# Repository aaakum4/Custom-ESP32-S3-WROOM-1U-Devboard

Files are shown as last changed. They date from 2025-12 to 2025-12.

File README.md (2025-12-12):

# ESP32-S3 Devboard Project
This is my custom ESP32-S3-WROOM-1U devboard project. I loosely followed Kai’s guide, but made a bunch of changes along the way to fit the ESP32-S3 and to learn more about PCB design. The board includes USB-C power, a MicroSD slot, UART, JTAG, reset/boot buttons, and an I²C connector — plus some custom Gojo artwork because why not.

## BOM (Initial Planning)
- 2.4GHz antenna (https://www.ebay.com.au/itm/227057783591?itemid=526207835011_227057783591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)

- Touch Screen (https://core-electronics.com.au/2-8-tft-display-240x320-with-capacitive-touchscreen.html)
A possible later addition

- USB-C Power (https://jlcpcb.com/partdetail/Korean_HropartsElec-TYPE_C_31_M12/C165948)

- Switch (https://jlcpcb.com/partdetail/XUNPU-TS_1088AR02016/C720477)

- https://www.arrow.com/en/products/1040310811/molex?utm_source=chatgpt.com

- https://core-electronics.com.au/male-pin-header-2-54mm-1x40.html

** Note much of these aren't used, but I thought I'd leave them here in-case anybody wants to do a similar project, here are some ideas.

## Bill of Materials (BOM)

BOM
** This list is by no means perfect.

## Development Journal
Here’s the whole journey from start to finish.

## Researching Devboards
Before I even started, I had to figure out what a devboard actually is and what they’re used for. I knew I wanted to make my own, but I didn’t know much beyond that.
I spent a while reading, asking ChatGPT questions, and checking out examples online. I also made a plan for how my board would differ from the guide.



## Power System & USB-C
I started wiring up the power section first. At one point I went down the rabbit hole of trying to use a buck switching regulator, but eventually realised I was overcomplicating things.
So I scrapped that and switched to the MCP1700 LDO instead — way simpler and fits the project better.





## First Schematic Pass
Once I switched to the ESP32-S3 (instead of the RP2040 used in the guide), things got a lot more complicated. The datasheet helped, but there were still a ton of questions.
With help from Slack and ChatGPT, I put together the first full version of the schematic. Definitely not perfect, but it was a solid starting point.



## Finalising the Schematic
After some feedback from Reddit, I made a bunch of improvements and finally wrapped the schematic up.
At this point the board had everything I wanted: USB-C, MicroSD, UART, JTAG, reset/boot buttons, and I²C.
The hardest part was honestly just knowing whether what I did was correct, but the community feedback helped a ton.



## Footprint Assignment
Assigning footprints was next. Most were easy thanks to the guide, but a couple (like the MicroSD slot and ferrite bead) weren’t.
After some datasheet hunting, I got them sorted out without too much trouble.



## Organising Components
This part was surprisingly fun. At first I felt overwhelmed by the wall of random capacitors and resistors, but after spending a bit of time on it everything started to make sense.



## Routing + Adding Artwork
Routing took forever — easily the longest part. This is only the second PCB I’ve ever routed, so I spent a lot of time learning and undoing mistakes.
Two big things I learned:
- USB D+ and D− need to be the same length
- MicroSD lines should avoid vias if possible
After a bunch of restarts and hours of routing, I finally got it into a place I’m happy with.
** Note: A good peice of advice I got from Kai's guide was to not route ground and instead do a ground fill, this saved alot of time and actally looks really nice.
I also added Gojo artwork on the front and back because the board needed some personality.
Another important part was removing alot of the labeling like 'C6' for capacitor 6, it makes the board look alot cleaner.







## Creating the Production ZIP
Before exporting anything, I did a full DRC check and gave the whole PCB a final look over.
The Gerbers and drill files exported fine, but the BOM and footprint position files needed their headers renamed so the manufacturer will accept them:
Footprint Position Fixes
- Ref → Designator
- PosX → Mid X
- PosY → Mid Y
- Rot → Rotation
- Side → Layer

BOM Fix
- Designation → Comment

After fixing those, I zipped everything up into a production-ready file.



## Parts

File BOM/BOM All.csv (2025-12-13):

BOM Table
JLCPCB BOM Tool - BOM Matching
BOM name_Devboard Routed Backup-JLCPCB Assembly Order.xlsx |  |  | Download Time_2025-12-13 15:56:26 |  |  |  | * Our matching results are updated in real-time, but stock and prices may change. If it's been over 24 hours, please re-match before placing your order.
PCB Assembled Qty_5 |  |  | Est. Total Price_3.9206
Your BOM |  |  |  |  | Matched Parts |  |  |  |  |  |  | Order Information
Top Designator | Bottom Designator | Comment | Footprint | JLCPCB Part # | Matches | Part # | Manufacturer | Footprint | Description | Category | Warning | JLCPCB Part # | Product link | Lib Type | Qty | Source | Total Price ($)
C3,C5,C7,C6 |  | 0.1uF | C_0402_1005Metric |  | Select by Customer | CL05B104KO5NNNC | Samsung Electro-Mechanics | 402 | 100nF 16V X7R ±10% 0402 Multilayer Ceramic Capacitors MLCC - SMD/SMT ROHS | Multilayer Ceramic Capacitors MLCC - SMD/SMT | 1.The comment (CL05B104KO5NNNC) of this part does not match the one (0.1uF) provided in your BOM. Please confirm; | C1525 | https://jlcpcb.com/partdetail/1877-CL05B104KO5NNNC/C1525 | Basic | 8 | 8 JLCPCB | 0.0096
C4 |  | 22uF | C_0603_1608Metric |  | Select by Customer | CL10A226MP8NUNE | Samsung Electro-Mechanics | 603 | 10V 22uF X5R ±20% 0603 Multilayer Ceramic Capacitors MLCC - SMD/SMT ROHS | Multilayer Ceramic Capacitors MLCC - SMD/SMT |  | C86295 | https://jlcpcb.com/partdetail/87471-CL10A226MP8NUNE/C86295 | Extended | 20 | 20 JLCPCB | 0.288
C8,C2,C1 |  | 10uF | C_0603_1608Metric |  | Select by Customer | CL10A106KP8NNNC | Samsung Electro-Mechanics | 603 | 10V 10uF X5R ±10% 0603 Multilayer Ceramic Capacitors MLCC - SMD/SMT ROHS | Multilayer Ceramic Capacitors MLCC - SMD/SMT |  | C19702 | https://jlcpcb.com/partdetail/20411-CL10A106KP8NNNC/C19702 | Basic | 6 | 6 JLCPCB | 0.0336
FB1 |  | FerriteBead | L_Walsin_WLFM201209x |  | Select by Customer | BLM21PG221SN1D | Murata Electronics | 805 | 1 220½@100MHz 2A 45m½ ±25% 0805 Ferrite Beads ROHS | Ferrite Beads |  | C85840 | https://jlcpcb.com/partdetail/MurataElectronics-BLM21PG221SN1D/C85840 | Extended | 20 | 20 JLCPCB | 0.316
J1 |  | USB_C_Receptacle_USB2.0_14P | USB_C_Receptacle_HRO_TYPE-C-31-M-12 |  | Select by Customer | TYPE-C-31-M-12 | Korean Hroparts Elec | SMD | 1 16P 5A Female Type-C SMD USB Connectors ROHS | USB Connectors |  | C165948 | https://jlcpcb.com/partdetail/Korean_HropartsElec-TYPE_C_31_M12/C165948 | Extended | 2 | 2 JLCPCB | 0.3388
J3,J7,J2 |  | Conn_01x04 | PinHeader_1x04_P2.54mm_Vertical |  | Select by Customer | 2.54-1*40P__ | BOOMELE(Boom Precision Elec) | __,P=2.54mm | -25_~+85_ 1 1x40P 2.54mm 2.5mm 3A 3mm 40P 6mm Black Brass Gold Pin Header Through Hole Plugin,P=2.54mm Pin Headers ROHS | Pin Headers | 1.Multiple lines in the BOM have been matched to the same part. Please check if the matching is correct. ; | C2337 | https://jlcpcb.com/partdetail/2712-2_54_1_40P/C2337 | Extended | 0 | 0 JLCPCB | 0
J6,J5 |  | Conn_01x14 | PinHeader_1x14_P2.54mm_Vertical |  | Select by Customer | 2.54-1*40P__ | BOOMELE(Boom Precision Elec) | __,P=2.54mm | -25_~+85_ 1 1x40P 2.54mm 2.5mm 3A 3mm 40P 6mm Black Brass Gold Pin Header Through Hole Plugin,P=2.54mm Pin Headers ROHS | Pin Headers | 1.Multiple lines in the BOM have been matched to the same part. Please check if the matching is correct. ; | C2337 | https://jlcpcb.com/partdetail/2712-2_54_1_40P/C2337 | Extended | 0 | 0 JLCPCB | 0
J4 |  | Micro_SD_Card | microSD_HC_Molex_104031-0811 |  | Select by Customer | 473521001 | MOLEX | SMD | -40_~+85_ Connector and Ejector MicroSD Card (TF Card) Push-Push SMD SD Card / Memory Card Connector ROHS | SD Card / Memory Card Connector |  | C293569 | https://jlcpcb.com/partdetail/MOLEX-473521001/C293569 | Extended | 2 | 2 JLCPCB | 1.869
R2,R1 |  | 5.1k | R_0402_1005Metric |  | Select by Customer | 0402WGF5101TCE | UNI-ROYAL(Uniroyal Elec) | 402 | -55_~+155_ 5.1k½ 50V 62.5mW Thick Film Resistor ±1% ±100ppm/_ 0402 Chip Resistor - Surface Mount ROHS | Chip Resistor - Surface Mount |  | C25905 | https://jlcpcb.com/partdetail/26648-0402WGF5101TCE/C25905 | Basic | 4 | 4 JLCPCB | 0.002
R4,R3 |  | 27 | R_0402_1005Metric |  | Select by Customer | 0402WGF270JTCE | UNI-ROYAL(Uniroyal Elec) | 402 | -55_~+155_ 27½ 50V 62.5mW Thick Film Resistor ±1% ±100ppm/_ 0402 Chip Resistor - Surface Mount ROHS | Chip Resistor - Surface Mount | 1.The comment (0402WGF270JTCE) of this part does not match the one (27) provided in your BOM. Please confirm; | C25100 | https://jlcpcb.com/partdetail/25843-0402WGF270JTCE/C25100 | Extended | 20 | 20 JLCPCB | 0.012
R5,R9,R10,R11,R12,R13,R7 |  | 10k | R_0402_1005Metric |  | Select by Customer | 0402WGF1002TCE | UNI-ROYAL(Uniroyal Elec) | 402 | -55_~+155_ 10k½ 50V 62.5mW Thick Film Resistor ±1% ±100ppm/_ 0402 Chip Resistor - Surface Mount ROHS | Chip Resistor - Surface Mount | 1.The comment (0402WGF1002TCE) of this part does not match the one (10k) provided in your BOM. Please confirm; | C25744 | https://jlcpcb.com/partdetail/26487-0402WGF1002TCE/C25744 | Basic | 14 | 14 JLCPCB | 0.007
R6 |  | 0 | R_0402_1005Metric |  | Select by Customer | PA0402-R-070RL | YAGEO | 402 | -55_~+125_ 0½ 62.5mW ±150ppm/_ 0402 Chip Resistor - Surface Mount ROHS | Chip Resistor - Surface Mount | 1.The comment (PA0402-R-070RL) of this part does not match the one (0) provided in your BOM. Please confirm; | C4044221 | https://jlcpcb.com/partdetail/YAGEO-PA0402_R070RL/C4044221 | Extended | 5 | 5 JLCPCB | 0.642
R8 |  | 1M | R_0603_1608Metric |  | Select by Customer | 0603WAF1004T5E | UNI-ROYAL(Uniroyal Elec) | 603 | -55_~+155_ 100mW 1M½ 75V Thick Film Resistor ±1% ±100ppm/_ 0603 Chip Resistor - Surface Mount ROHS | Chip Resistor - Surface Mount | 1.The comment (0603WAF1004T5E) of this part does not match the one (1M) provided in your BOM. Please confirm; | C22935 | https://jlcpcb.com/partdetail/23662-0603WAF1004T5E/C22935 | Basic | 2 | 2 JLCPCB | 0.0022
R15,R14 |  | 4.7k | R_0402_1005Metric |  | Select by Customer | 0402WGF470JTCE | UNI-ROYAL(Uniroyal Elec) | 402 | -55_~+155_ 47½ 50V 62.5mW Thick Film Resistor ±1% ±100ppm/_ 0402 Chip Resistor - Surface Mount ROHS | Chip Resistor - Surface Mount | 1.The comment (0402WGF470JTCE) of this part does not match the one (4.7k) provided in your BOM. Please confirm; | C25118 | https://jlcpcb.com/partdetail/25861-0402WGF470JTCE/C25118 | Extended | 20 | 20 JLCPCB | 0.012
SW1,SW2 |  | SW_Push | SW_Push_SPST_NO_Alps_SKRK |  | Select by Customer | TS-1088-AR02016 | XUNPU | SMD,4x3mm | -30_~+80_ 1.6N 100,000 Cycles 12V 2mm 3mm 4mm 50mA Black Round Button SMD(SMT) Tab SPST Surface Mount,Vertical Without Bracket SMD,4x3mm Tactile Switches ROHS | Tactile Switches |  | C720477 | https://jlcpcb.com/partdetail/XUNPU-TS_1088AR02016/C720477 | Basic | 4 | 4 JLCPCB | 0.17
U1 |  | ESP32-S3-WROOM-1U | ESP32-S3-WROOM-1U |  | Select by Customer | ESP32-S3-WROOM-1U-N8 | Espressif Systems | SMD,19.2x18mm | -40_~+85_ -98.2dBm 2.4GHz 20.5dBm 355mA 3V~3.6V 95mA Bluetooth5.0 ESP32-S3 UART SMD,19.2x18mm WiFi Modules ROHS | WiFi Modules |  | C2980297 | https://jlcpcb.com/partdetail/3401549-ESP32_S3_WROOM_1UN8/C2980297 | Extended | 0 | 0 JLCPCB | 0
U2 |  | MCP1700x-120xxMB | SOT-89-3 |  | Select by Customer | HT7533-1 | Holtek Semicon | SOT-89-3 | -40_~+85_@(Ta) 1 100mA 2.5uA 25mV@(1mA) 3.3V 30V Fixed Positive SOT-89-3 Voltage Regulators - Linear, Low Drop Out (LDO) Regulators ROHS | Voltage Regulators - Linear, Low Drop Out (LDO) Regulators |  | C14289 | https://jlcpcb.com/partdetail/HoltekSemicon-HT75331/C14289 | Basic | 2 | 2 JLCPCB | 0.2184
JLCPCB Part | Layers | Dimensions | QTY | Thickness | Cost
PCB Board | 2 Layers | 36 mm* 52.7 mm | 5 | 1.6mm | $2.00
EBay Part | Comment | QTY | Cost
Antenna | 2.4GHz Antenna with U.FL Connector | 1 | AU $7.01 USD $4.67
1x40 Pin Header Breakaways | 10pcs 1x40pin 2.54mm Male PCB Single Row Straight Header Strip Connector | 1 | AU $6.48 USD $4.31
LCSC Part | Comment | QTY | Cost (Before shipping) | Cost (After shipping)
ESP32-S3-Wroom-1U-N8 | ESP32-S3-WROOM-1U-N8 2.4GHz ESP32-S3 -98.2dBm SMD | 2 | USD $9.34 | USD $21.06

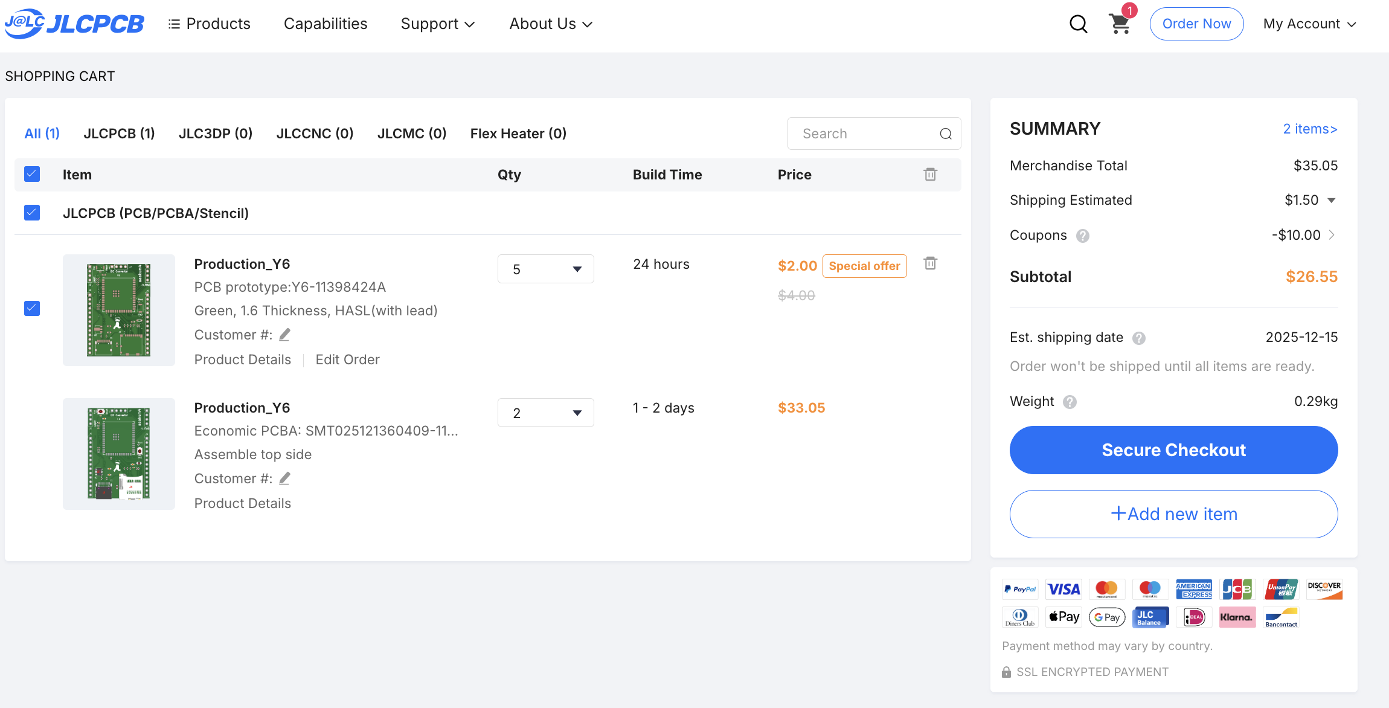
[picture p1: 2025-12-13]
BOM/JLCPCB.png

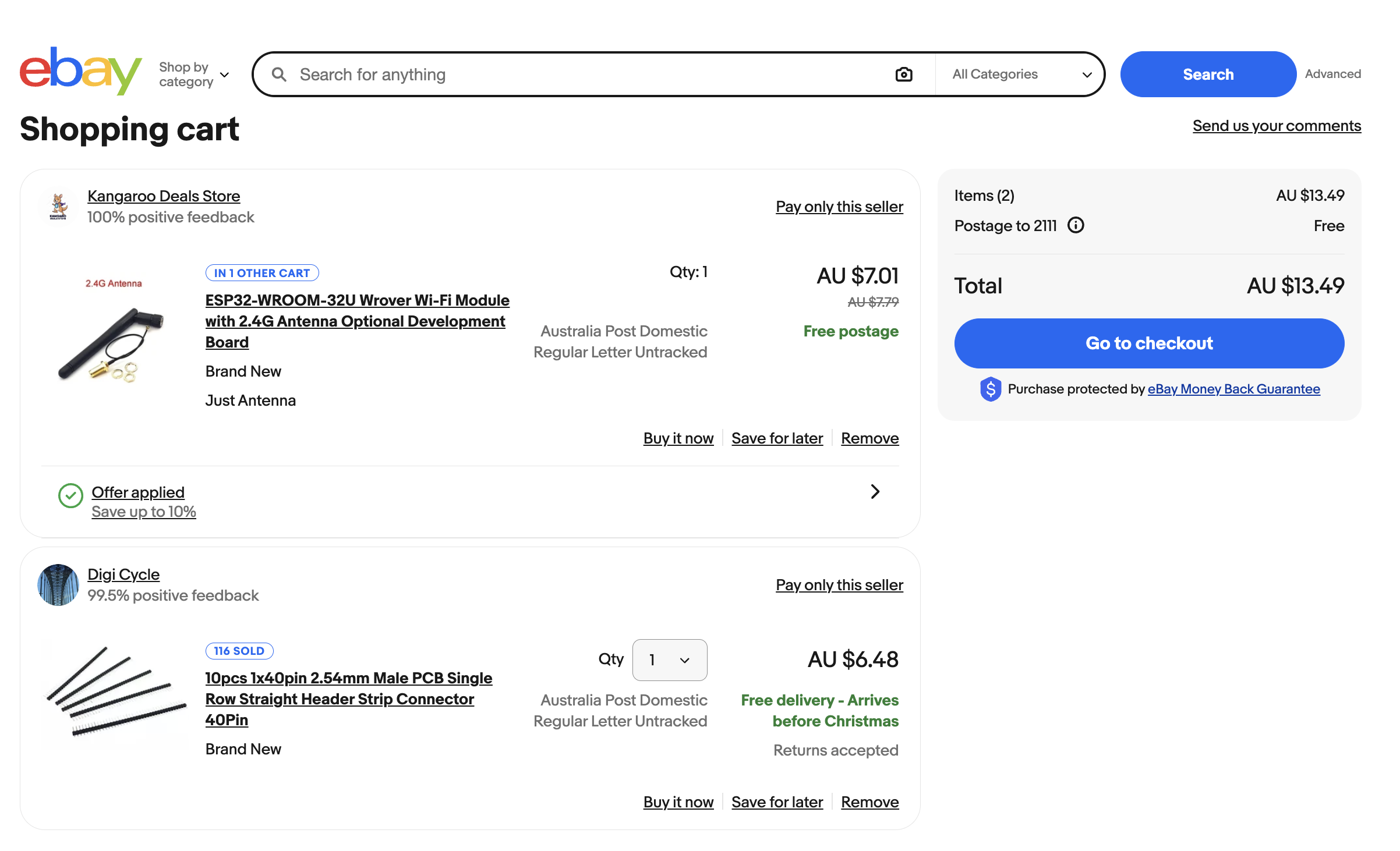
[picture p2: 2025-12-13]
BOM/Antenna + Pin Headers.png

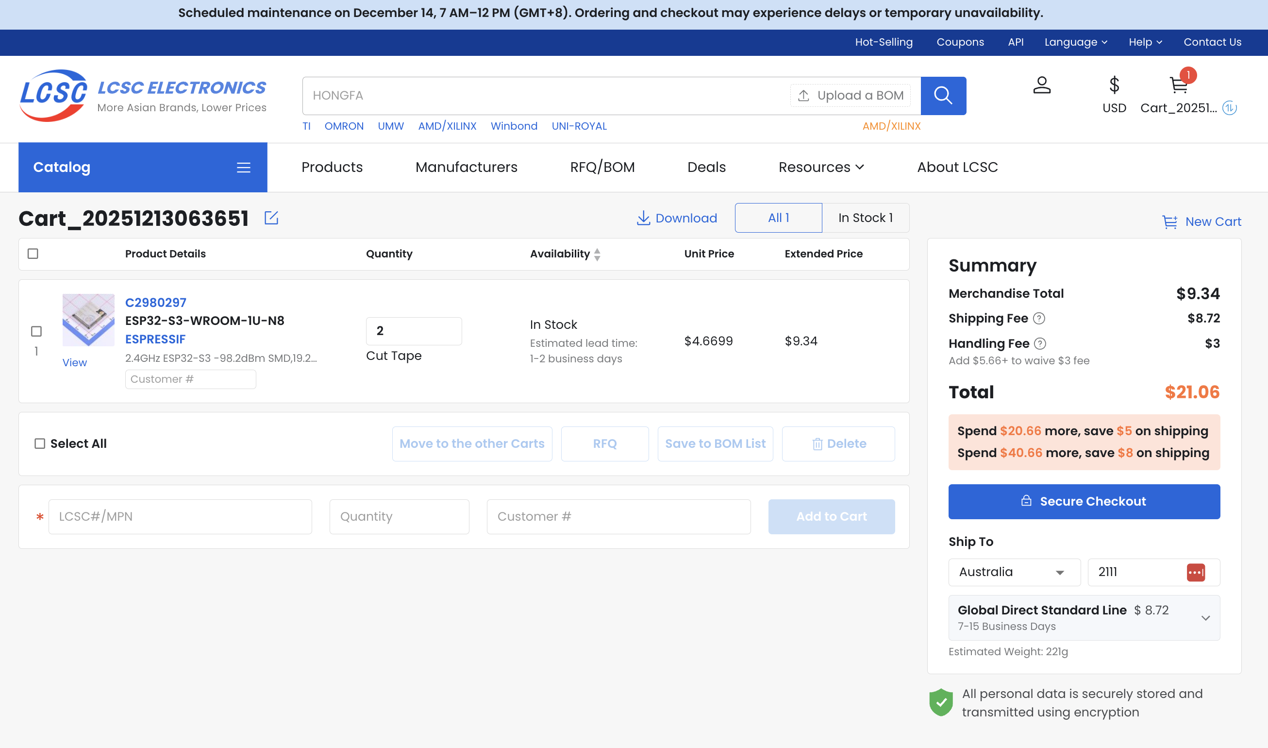
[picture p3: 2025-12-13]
BOM/ESP32.png

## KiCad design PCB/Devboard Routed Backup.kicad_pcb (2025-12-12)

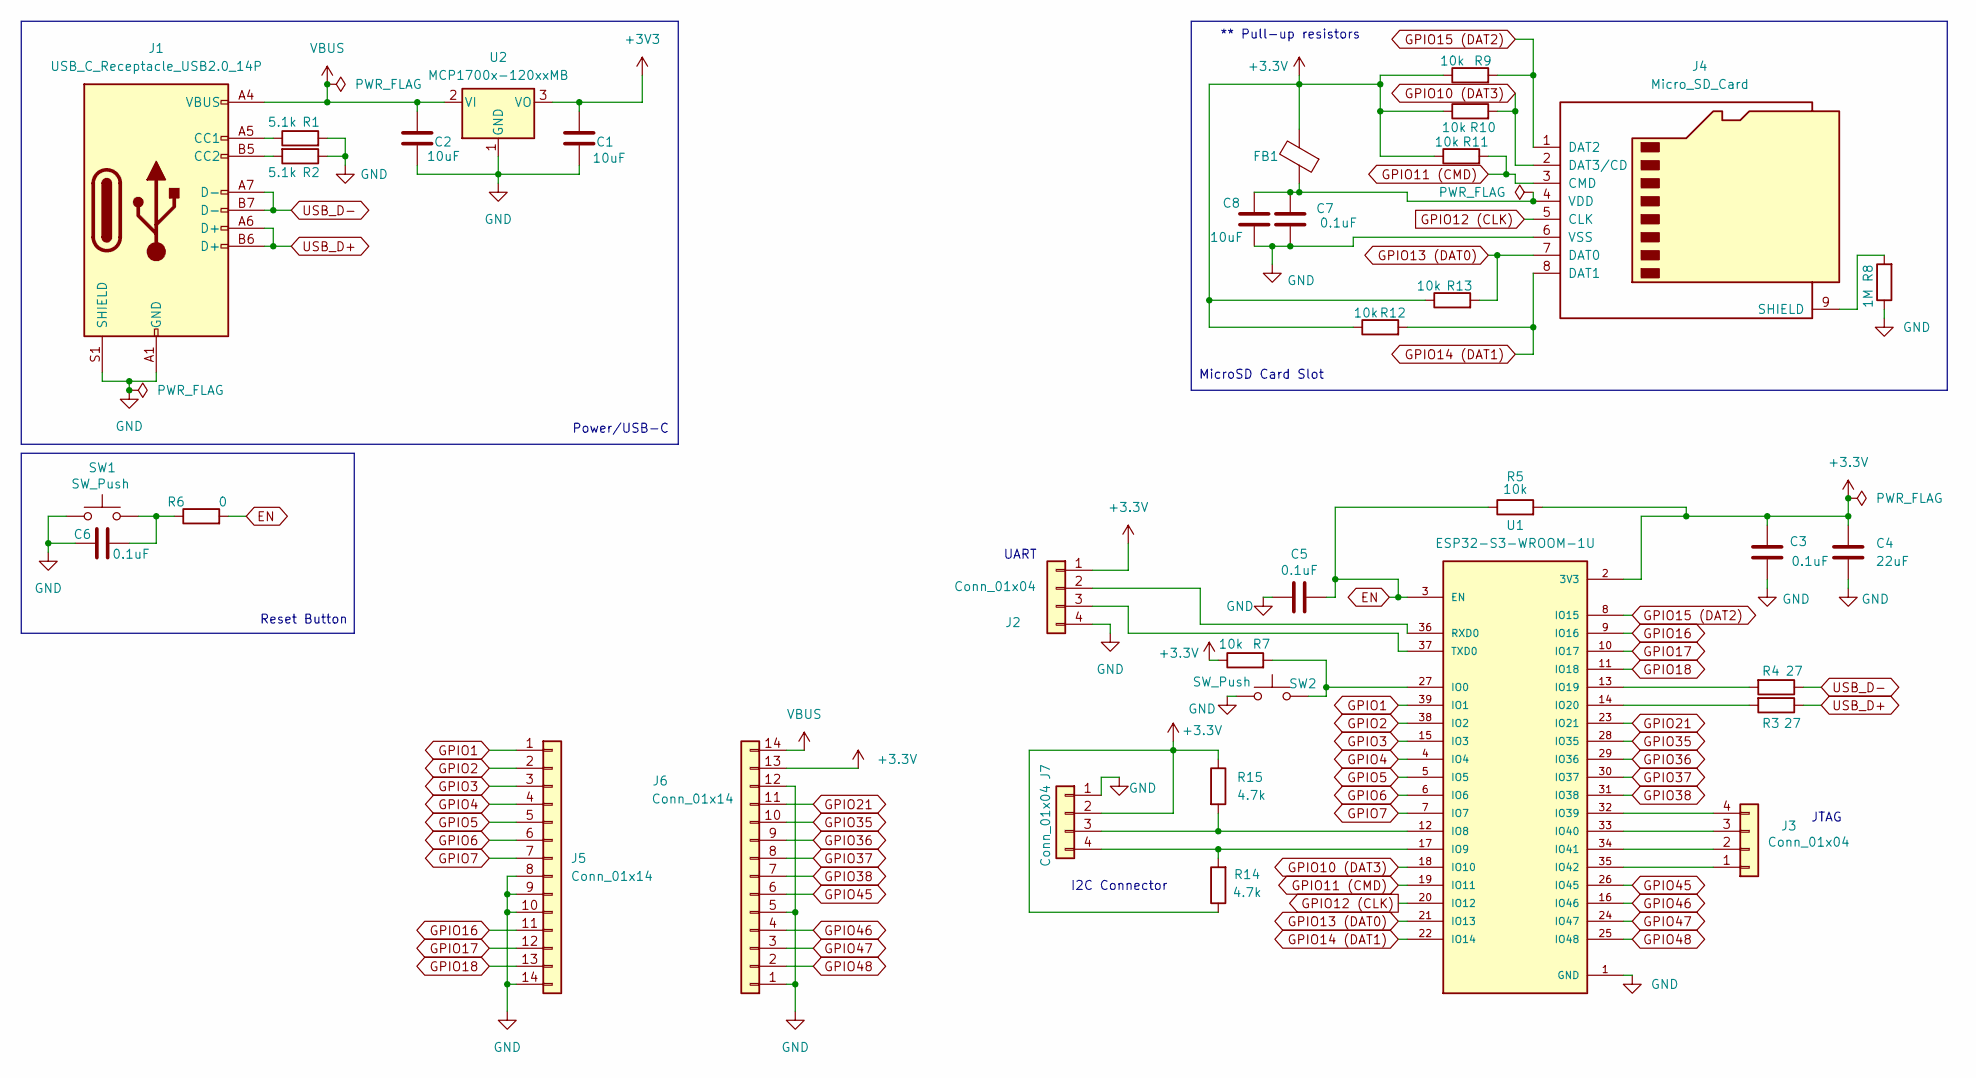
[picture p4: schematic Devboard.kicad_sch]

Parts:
C1, C2, C8: 10uF; C_0603_1608Metric
C3, C5, C6, C7: 0.1uF; C_0402_1005Metric
C4: 22uF; C_0603_1608Metric
FB1: FerriteBead; L_Walsin_WLFM201209x
J1: USB_C_Receptacle_USB2.0_14P; USB_C_Receptacle_HRO_TYPE-C-31-M-12
J2, J3: Conn_01x04; PinHeader_1x04_P2.54mm_Vertical
J4: Micro_SD_Card; microSD_HC_Molex_104031-0811
J5, J6: Conn_01x14; PinHeader_1x14_P2.54mm_Vertical
J7: Conn_01x04; JST_SH_SM04B-SRSS-TB_1x04-1MP_P1.00mm_Horizontal
R1, R2: 5.1k; R_0402_1005Metric
R3, R4: 27; R_0402_1005Metric
R5, R7, R9, R10, R11, R12, R13: 10k; R_0402_1005Metric
R6: 0; R_0402_1005Metric
R8: 1M; R_0603_1608Metric
R14, R15: 4.7k; R_0402_1005Metric
SW1, SW2: SW_Push; SW_Push_SPST_NO_Alps_SKRK
U1: ESP32-S3-WROOM-1U; PARTREV v0.6
U2: MCP1700x-120xxMB; SOT-89-3

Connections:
+3.3V: C3.1, C4.1, FB1.2, J2.1, J6.13, J7.2, R5.2, R7.1, R9.1, R10.1, R11.1, R12.1, R13.1, R14.1, R15.1, U1.2 (3V3)
+3V3: C1.1, U2.3 (VO)
EN: C5.2, R5.1, R6.2, U1.3 (EN)
GND: C1.2, C2.2, C3.2, C4.2, C5.1, C6.1, C7.1, C8.2, J1.A1 (GND), J1.A12 (GND), J1.B1 (GND), J1.B12 (GND), J1.S1 (SHIELD), J2.4, J4.6 (VSS), J5.8, J5.9, J5.10, J5.14, J6.1, J6.5, J6.12, J7.1, R1.2, R2.1, R8.1, SW1.1, SW2.1, U1.1 (GND), U1.40 (GND), U1.41_1 (GND), U1.41_2 (GND), U1.41_3 (GND), U1.41_4 (GND), U1.41_5 (GND), U1.41_6 (GND), U1.41_7 (GND), U1.41_8 (GND), U1.41_9 (GND), U2.1 (GND)
GPIO1: J5.1, U1.39 (IO1)
GPIO2: J5.2, U1.38 (IO2)
GPIO3: J5.3, U1.15 (IO3)
GPIO4: J5.4, U1.4 (IO4)
GPIO5: J5.5, U1.5 (IO5)
GPIO6: J5.6, U1.6 (IO6)
GPIO7: J5.7, U1.7 (IO7)
GPIO10 (DAT3): J4.2 (DAT3/CD), R10.2, U1.18 (IO10)
GPIO11 (CMD): J4.3 (CMD), R11.2, U1.19 (IO11)
GPIO12 (CLK): J4.5 (CLK), U1.20 (IO12)
GPIO13 (DAT0): J4.7 (DAT0), R13.2, U1.21 (IO13)
GPIO14 (DAT1): J4.8 (DAT1), R12.2, U1.22 (IO14)
GPIO15 (DAT2): J4.1 (DAT2), R9.2, U1.8 (IO15)
GPIO16: J5.11, U1.9 (IO16)
GPIO17: J5.12, U1.10 (IO17)
GPIO18: J5.13, U1.11 (IO18)
GPIO21: J6.11, U1.23 (IO21)
GPIO35: J6.10, U1.28 (IO35)
GPIO36: J6.9, U1.29 (IO36)
GPIO37: J6.8, U1.30 (IO37)
GPIO38: J6.7, U1.31 (IO38)
GPIO45: J6.6, U1.26 (IO45)
GPIO46: J6.4, U1.16 (IO46)
GPIO47: J6.3, U1.24 (IO47)
GPIO48: J6.2, U1.25 (IO48)
unnamed: C6.2, R6.1, SW1.2
unnamed: J1.A5 (CC1), R1.1
unnamed: J1.B5 (CC2), R2.2
unnamed: J2.2, U1.36 (RXD0)
unnamed: J2.3, U1.37 (TXD0)
unnamed: J3.1, U1.35 (IO42)
unnamed: J3.2, U1.34 (IO41)
unnamed: J3.3, U1.33 (IO40)
unnamed: J3.4, U1.32 (IO39)
unnamed: J4.9 (SHIELD), R8.2
unnamed: C7.2, C8.1, FB1.1, J4.4 (VDD)
unnamed: J7.3, R15.2, U1.12 (IO8)
unnamed: J7.4, R14.2, U1.17 (IO9)
unnamed: R7.2, SW2.2, U1.27 (IO0)
unnamed: R4.2, U1.13 (IO19)
unnamed: R3.2, U1.14 (IO20)
USB_D+: J1.A6 (D+), J1.B6 (D+), R3.1
USB_D-: J1.A7 (D-), J1.B7 (D-), R4.1
VBUS: C2.1, J1.A4 (VBUS), J1.A9 (VBUS), J1.B4 (VBUS), J1.B9 (VBUS), J6.14, U2.2 (VI)

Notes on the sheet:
I2C Connector
** Pull-up resistors
Reset Button
Power/USB-C
JTAG
UART
MicroSD Card Slot

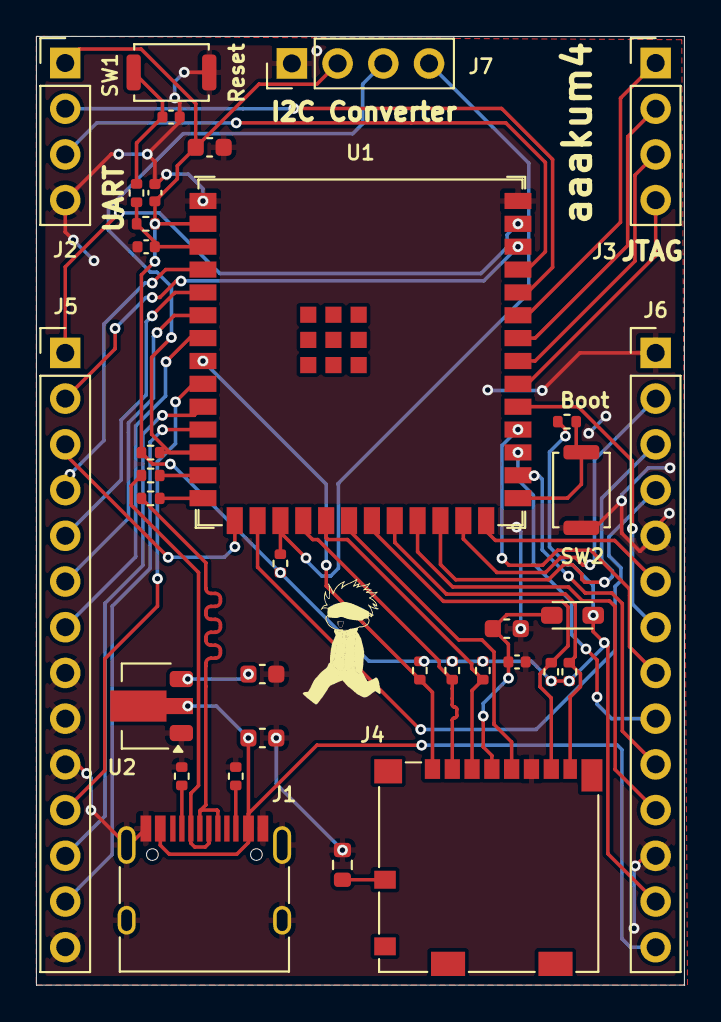
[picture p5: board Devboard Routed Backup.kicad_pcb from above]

Board: 2 copper layers, 36.0 x 52.7 mm, 35 parts (0 on the bottom side), 48 nets.

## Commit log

2025-12-09 Update README with initial BOM for Devboard
    Added initial BOM items with links for components.
2025-12-09 Fix formatting of BOM item in README
2025-12-11 Fix tactile switch link in README
    Updated link for the tactile switch in the BOM section.
2025-12-11 Update BOM section with new components and links
    Added additional components to the BOM section with links.
2025-12-12 Revise README for ESP32-S3 Devboard project
    Updated project description and added sections for development journal and research.
2025-12-12 Enhance README with development journey and BOM
    Updated README to include additional sections and images detailing the development process.
2025-12-12 Added relevant files
    [Devboard Routed Backup.kicad_pcb, Devboard.kicad_sch]
2025-12-13 Added BOM
    [BOM.csv]
2025-12-13 Updated BOM
    [BOM All.csv, BOM.csv]
